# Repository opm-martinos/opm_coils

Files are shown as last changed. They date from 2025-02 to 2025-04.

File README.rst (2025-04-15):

OPM Nulling coil design
=======================

This repository hosts Python code for design of biplanar coils
for nulling uniform fields for operation of Optically Pumped Magnetometers (OPMs)



Installation
^^^^^^^^^^^^

We recommend creating a virtual environment. For example, using Anaconda,
we can create a virtual environment using the following command::

    $ conda create -n opmcoils -c conda-forge python=3.9

Then, inside the environment::

    $ conda activate opmcoils

Install ``opmcoils`` by doing::

    $ pip install .

Advanced users or contributors may add the ``-e`` flag to create an editable install and they
may also install the dependencies required to build the documentation::

    $ pip install -e .[docs]

or:

    $ pip install -e .[full]

Note that `Mosek <https://www.mosek.com/>`_ is required for the optimization
of the coil design. Please refer to the documentation for installation
instructions.

Usage
^^^^^

Please check the examples/ directory

License
^^^^^^^

The software is distributed under BSD 3-Clause and the hardware is distributed
under CERN-OHL-S (strongly reciprocal) licenses. Please include the appropriate
license when re-distributing any parts of the hardware/software.

Citation
^^^^^^^^

If you use the data, scripts, or hardware designs from this repository, please
cite::

    Jas M., Kamataris J., Matsubara T., Dong C., Motta G.,
    Sohrabpour A., Ahlfors S.P., Hamalainen M., Okada Y., and Sundaram P..
    Biplanar nulling coil system for OPM-MEG using printed circuit boards.
    BioRxiv 2025.02.19.638883. 2025.

Funding
^^^^^^^

This work was supported by NIH grants P41EB030006, 1R21NS140619-01, 2R01NS104585-05,
1R01NS112183-01A1, and S10OD030469.

.. toctree::
   :hidden:

   Example gallery<auto_examples/index>
   API<api>
   PCB design files<https://github.com/opm-martinos/opm_coils/tree/main/hardware>
   Coil assembly<assembly>

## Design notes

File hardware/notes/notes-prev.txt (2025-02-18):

(we've done the y coil)

each u-channel = 0.313 in = 7.9502 mm = w

   8 mm
+........+........+........+........+........+        +........+........+........+........+........+ 
Gz       Bz       Gx       Bx       Gy       By       By      Gy        Bx       Gx       Bz      Gz
                                              |140.0 cm|
				    |--------- 140.8 cm -------|
                           |------------------ 141.6 cm -----------------|
		  |--------------------------- 142.4 cm ---------------------------|
         |------------------------------------ 143.2 cm ------------------------------------|
|--------------------------------------------- 144.0 cm --------------------------------------------|

N_suh = 50 (for all)

Gy
7.75 nT/m per mA
7.66 ohm
155.8 m

Bx 
1.47 nT/mA
10.68 ohm
217.36 m

Gx
7.5 nT/m per mA
7.82 ohm
159.312 m

Bz
6.41 nT per mA
8.08 ohm
164.48 m

Gz
15.26 nT/m per mA
5.4 ohm
110.1 m

By: printed

Gy: done

Bx: <--?

Gx: done

Gz: done (check TOP BOT , solder pad numbers for first vs second)

Bz: ---> done

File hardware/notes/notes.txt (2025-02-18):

(we've done the y coil)

each u-channel = 0.313 in = 7.9502 mm = w

   8 mm
+........+........+........+........+........+        +........+........+........+........+........+ 
Gz       Bz       Gx       Bx       Gy       By       By      Gy        Bx       Gx       Bz      Gz
                                              |140.0 cm|
                                    |--------- 140.8 cm -------|
                           |------------------ 141.6 cm -----------------|
                  |--------------------------- 142.4 cm ---------------------------|
         |------------------------------------ 143.2 cm ------------------------------------|
|--------------------------------------------- 144.0 cm --------------------------------------------|

N_suh = 50 (for all)

By: printed

Gy: 
'efficiency (nT/mA)': 7.94, 
'resistance (ohm)': 7.62, 
'length (m)': 155.11, 
(coil sz: 1.408)

Bx 
'efficiency (nT/mA)': 1.47
'resistance (ohm)': 10.67, 
'length (m)': 217.13, 
(coil sz: 1.417)

Gx
'efficiency (nT/mA)': 7.80, 
'resistance (ohm)': 7.70, 
'length (m)': 156.88,
(coil sz: 1.424)

Bz:
'efficiency (nT/mA)': 6.50,
'resistance (ohm)': 8.04,
'length (m)': 163.56,
(coil sz: 1.43)

Gz:
'efficiency (nT/mA)': -15.73, 
'resistance (ohm)': 5.36, 
'length (m)': 109.13,
(coil sz: 1.44)

Bx: done
Gx: done
Gy: done

Gz: 
Bz: 

Comments by Mainak

- check if the solder pads are aligned (Bx)
- Mainak: check the gradient targets
- Fix arrow in Bz inner loop
- Add arrow in Gz

Checklist of things to be checked

- check arrows are correctly pointed
- check length of the coil
- solder pad alignment
- power terminals in the correct corner (and aligned?)
- run DRC after shorting

Padma: 12/10/23 : last check before sending to hopetime

-- the power terminals on the By (already printed board): (X,Y) = (30,60)

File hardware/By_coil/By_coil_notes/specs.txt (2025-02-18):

***********
1.4441397313237125 nT / mA
10.468827952333154 ohm (5 mm trk, 2 oz cu)
N_contours = 30
835.5387467172762 uH
214.29075005017006 m

abs_error = 0.025 
lmax = 3
N_suh = 50
***********
-----------

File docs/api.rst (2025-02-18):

:orphan:

API
===

Design and manufacture nulling coils
^^^^^^^^^^^^^^^^^^^^^^^^^^^^^^^^^^^^

Optimize stream functions, discretize into current
loops, join interactively, and export to KiCAD.

.. currentmodule:: opmcoils

.. autosummary::
   :toctree: generated/

    BiplanarCoil
    get_sphere_points
    get_target_field

Evaluation metrics
^^^^^^^^^^^^^^^^^^

Evaluate performance using efficiency and homogeneity.

.. currentmodule:: opmcoils.metrics

.. autosummary::
    :toctree: generated/

    efficiency
    homogeneity

Simulating PCBs
^^^^^^^^^^^^^^^

Load the completed coil path from KiCAD and compute the
total magnetic field from a combination of PCBs.

.. currentmodule:: opmcoils.panels

.. autosummary::
    :toctree: generated/

    PCB
    PCBPanel
    load_panel
    combined_panel_field
    plot_field_colormap
    plot_panel_profile
    plot_panel
    plot_combined_panels

Data Analysis
^^^^^^^^^^^^^

Analyze the performance of a coil design.

.. currentmodule:: opmcoils.analysis

.. autosummary::
    :toctree: generated/

    get_good_chs
    load_remnant_fields
    add_ch_loc
    read_opm_info
    find_events

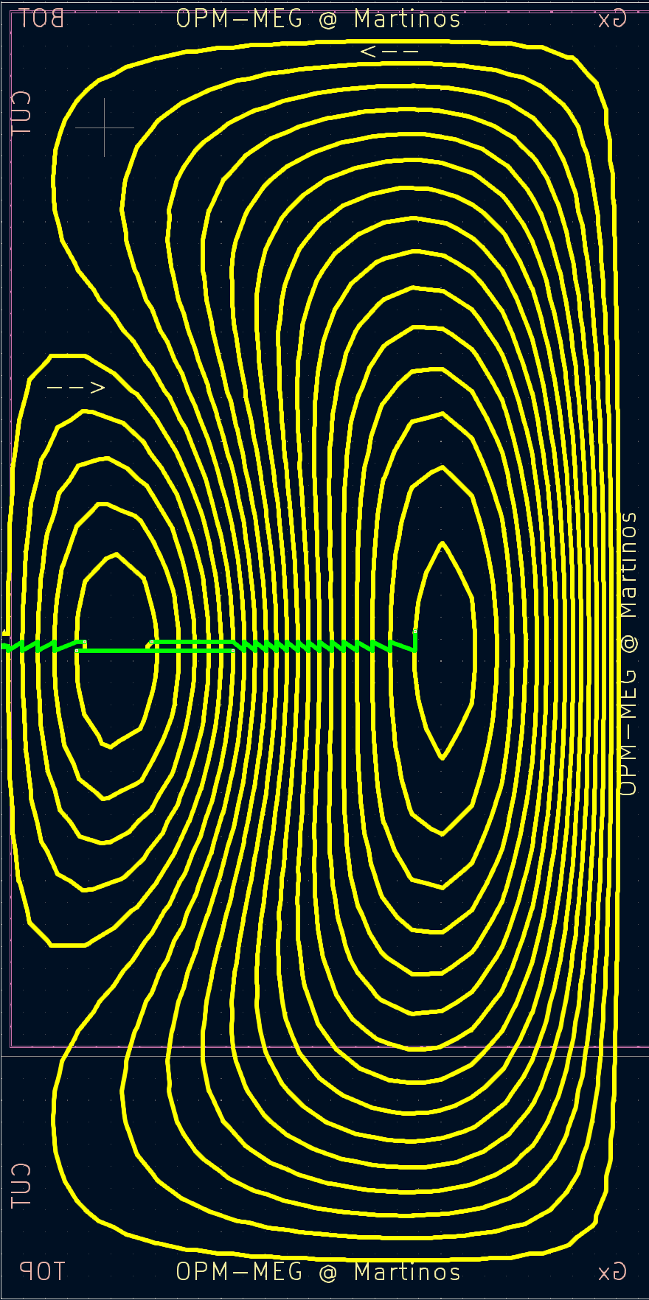
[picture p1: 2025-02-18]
hardware/notes/Gx_1st.png

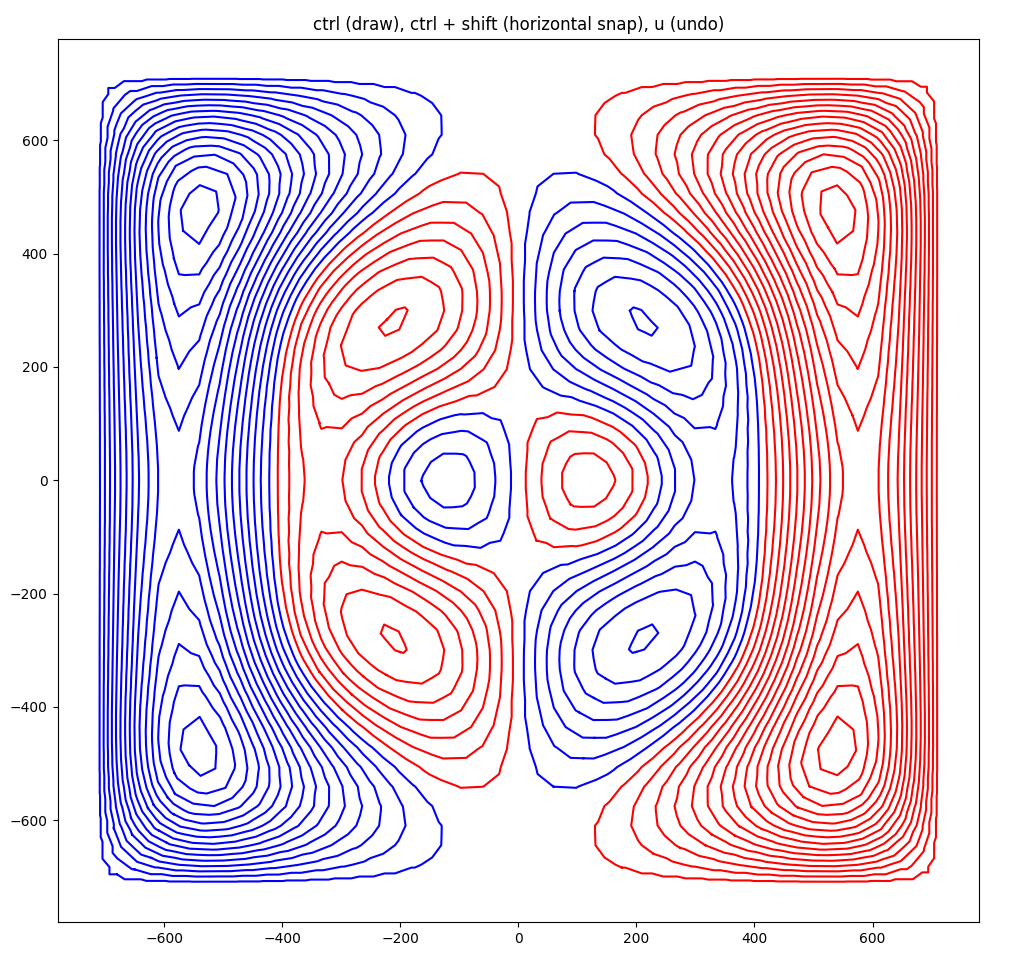
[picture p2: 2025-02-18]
hardware/notes/Bx.png

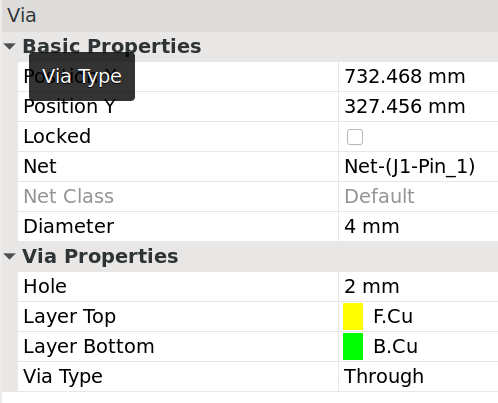
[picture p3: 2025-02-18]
hardware/notes/via_params.png

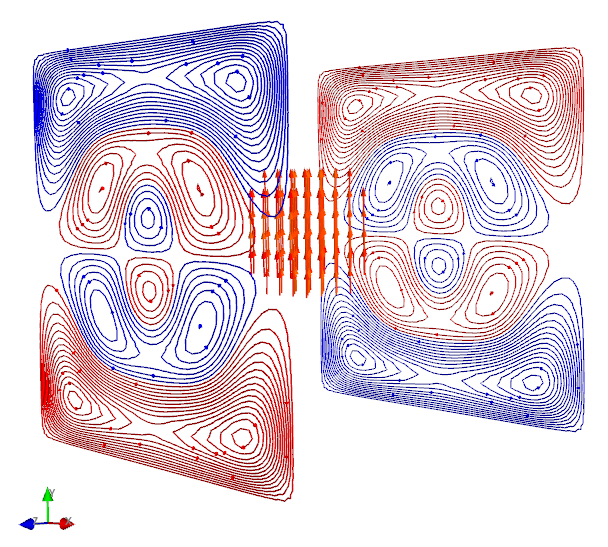
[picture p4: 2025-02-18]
hardware/By_coil/By_coil_notes/windings.png

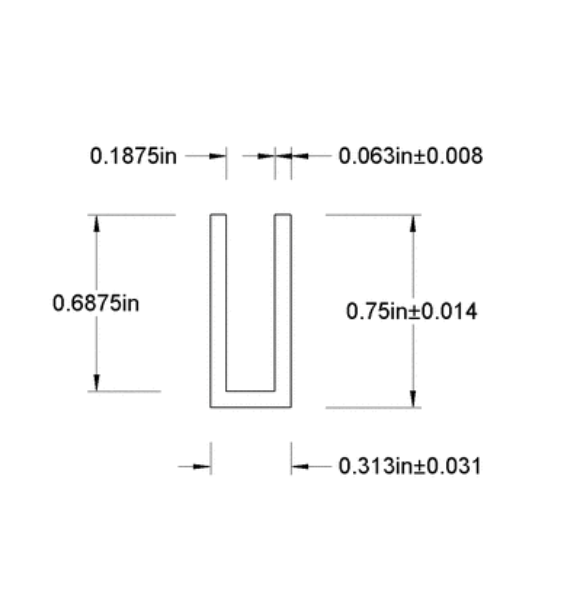
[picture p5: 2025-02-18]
hardware/notes/U-channel.png

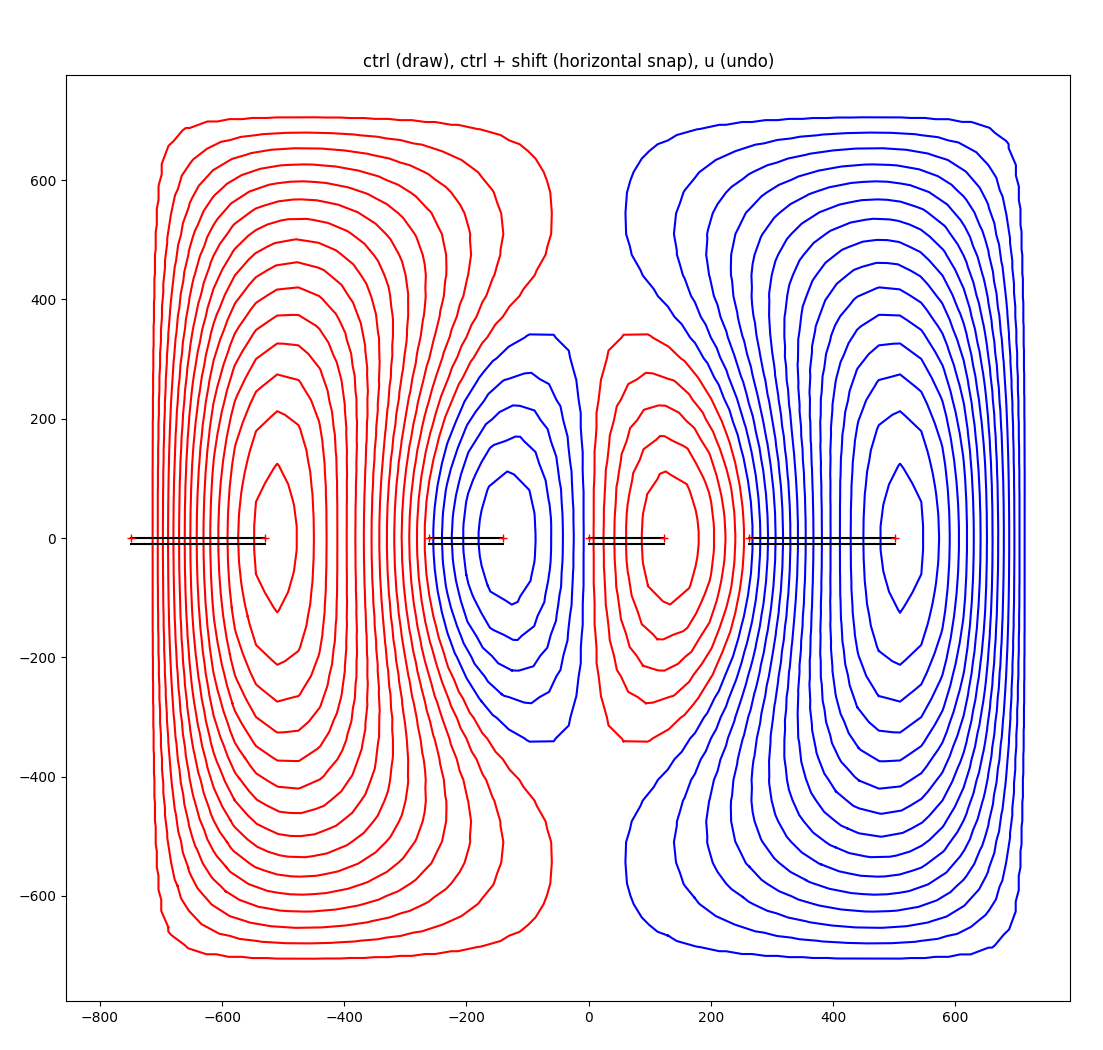
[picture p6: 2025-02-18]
hardware/notes/Gx_cuts.png

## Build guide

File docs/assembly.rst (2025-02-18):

Assembly
--------

Components
~~~~~~~~~~
Listed below are the components required for assembling the
scaffolding for the nulling coils.

.. raw:: html

   <iframe
   src="https://docs.google.com/spreadsheets/d/e/2PACX-1vTlF4ZdXIvoWgGOghj-Ay8ZZ6T5og1CqCico-cZ2VpzEsuoGG1OQPmc83smJqI1azGVGKqTVJGV9MdP/pubhtml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"
   width="100%" height="1500px">
   </iframe>

Steps for assembly
~~~~~~~~~~~~~~~~~~
.. raw:: html

   <iframe
   src="https://docs.google.com/spreadsheets/d/e/2PACX-1vTlF4ZdXIvoWgGOghj-Ay8ZZ6T5og1CqCico-cZ2VpzEsuoGG1OQPmc83smJqI1azGVGKqTVJGV9MdP/pubhtml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"
   width="100%" height="1850px">
   </iframe>
